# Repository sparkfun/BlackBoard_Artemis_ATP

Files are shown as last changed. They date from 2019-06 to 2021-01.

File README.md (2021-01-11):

**NOTE:** *This product has been retired from our catalog. There is an updated RedBoard version available: [DEV-15442](https://www.sparkfun.com/products/15442). If you are looking for more up-to-date info, please check out some of these resources to see how other users are still hacking and improving on this product version.*

* *[SparkFun Artemis Forum](https://forum.sparkfun.com/viewforum.php?f=167)*
* *[Comments Here on GitHub](https://github.com/sparkfun/BlackBoard_Artemis_ATP/issues)*

SparkFun BlackBoard Artemis ATP
============================

SparkFun BlackBoard Artemis ATP

[*SparkFun BlackBoard Artemis ATP (SPX-15412)*](https://www.sparkfun.com/products/15412)

The BlackBoard Artemis ATP is affectionately called 'All the Pins!' at SparkFun. The Artemis module has 48 GPIO and this board breaks out absolutely every one of them in a familiar Mega like form factor. What's with the silkscreen labels? They're all over the place. We decided to label the pins as they are assigned on the Apollo3 IC itself. This makes finding the pin with the function you desire a lot easier. Have a look at the [full pin map](https://cdn.sparkfun.com/assets/8/2/3/3/c/Apollo3_Pad_Mapping.pdf) from the Apollo3 datasheet. If you really need to test out the 4-bit SPI functionality of the Artemis you're going to need to access pins 4, 22, 23, and 26. Need to try out the differential ADC port 1? Pins 14 and 15. The BlackBoard Artemis ATP will allow you to flex the impressive capabilities of the Artemis module.

The BlackBoard Artemis ATP has the improved power conditioning and USB to serial that we've refined over the years on our BlackBoard line of products. A modern USB-C connector make programming easy. A Qwiic connector makes I<sup>2</sup>C easy. The ATP is fully compatible with SparkFun's Arduino core and can be programmed easily under the Arduino IDE. We've exposed the JTAG connector for more advanced users who prefer to use the power and speed of professional tools. If you need a *lot* of a GPIO with a simple to program, ready to go to market module, the ATP is the fix you need. We've added a digital MEMS microphone for folks wanting to experiment with always-on voice commands with TensorFlow and machine learning. We've even added a convenient jumper to measure current consumption for low power testing.

With 1M flash and 384k RAM you'll have plenty of room for your sketches. The Artemis module runs at 48MHz with a 96MHz turbo mode available and with Bluetooth to boot!

The SparkFun BlackBoard Artemis ATP is a powerful platform if you're interesting in testing out the full capabilities of the SparkFun Artemis module. If you're looking for more compact solution, be sure to checkout our Nano and Uno footprints for more hacker friendly products.

**Note:** We are actively working on getting FCC and compliance certifications for the SparkFun Artemis Module. Once our certifications are complete we will be moving the ATP to a RedBoard format with the FCC Certified version of the Artemis on board. *Please be aware* that this could happen as soon as a few weeks to a month so this BlackBoard version is for those of you who can't wait and want to start using the SparkFun Artemis as soon as possible!

Repository Contents
-------------------
* **/Hardware** - Eagle design files (.brd, .sch)

Documentation
-------------------
* **[BlackBoard Artemis ATP Hookup Guide](https://learn.sparkfun.com/tutorials/hookup-guide-for-the-blackboard-artemis-atp)** - Hookup Guide for the BlackBoard Artemis ATP
* **[Designing with the SparkFun Artemis](https://learn.sparkfun.com/tutorials/designing-with-the-sparkfun-artemis)** - Layout and design considerations when using the Artemis module.
* **[Artemis Development with Arduino](https://learn.sparkfun.com/tutorials/artemis-development-with-arduino)** - Introduction to the Arduino core for the Artemis Module.
* **[Ambiq Apollo3 SDK SetUp](https://learn.sparkfun.com/tutorials/using-sparkfun-edge-board-with-ambiq-apollo3-sdk)** - Getting set up with the Apollo3 Software Development Kit.
* **[CH340E USB to serial IC Drivers](https://www.sparkfun.com/ch340)**

License Information
-------------------

This product is _**open source**_! 

Please review the LICENSE.md file for license information. 

If you have any questions or concerns on licensing, please contact techsupport@sparkfun.com.

Please use, reuse, and modify these files as you see fit. Please maintain attribution to SparkFun Electronics and release any derivative under the same license.

Distributed as-is; no warranty is given.

- Your friends at SparkFun.

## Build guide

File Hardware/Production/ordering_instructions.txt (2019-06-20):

panel size, 226x175mm
PCB thickness, 1.6mm
number of layers, 2
soldermask color, Red
silkscreen color, White
oz copper, 1oz
finish, HASL lead free
stencils, top
pcs per panel, 6
min trace width, 0.177800mm / 0.007000in
min drill size, 0.304800mm / 0.012000in

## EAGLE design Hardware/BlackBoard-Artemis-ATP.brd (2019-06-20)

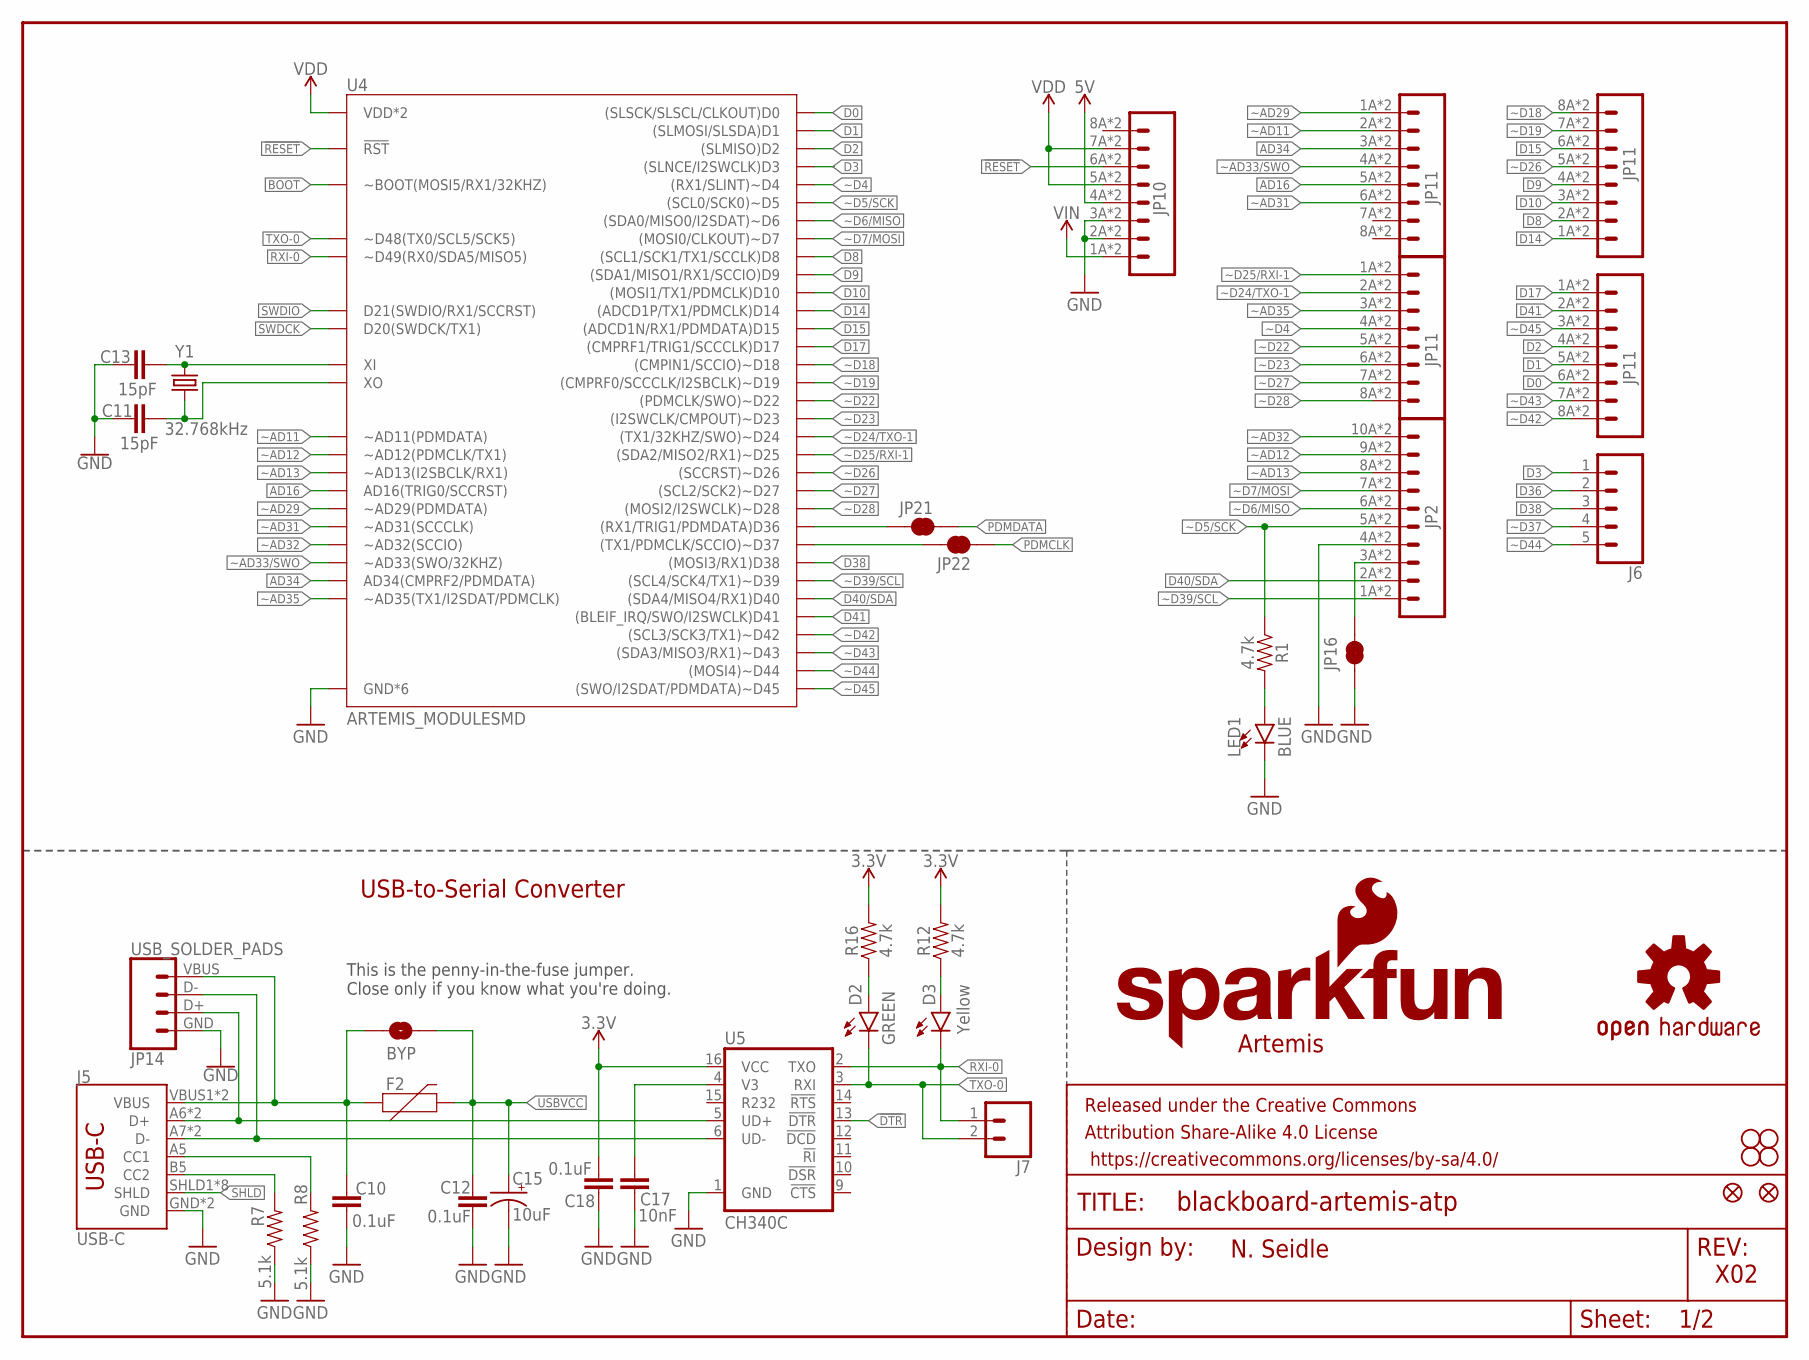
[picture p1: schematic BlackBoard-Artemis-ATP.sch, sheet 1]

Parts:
BYP: BYP; SMT-JUMPER_2_NO_SILK
C10, C12, C18: 0.1uF; 0603
C11, C13: 15pF; 0603
C15: 10uF; EIA3216
C17: 10nF; 0603
D2: GREEN; LED-1206
D3: Yellow; LED-1206
F2: 6V/2A; 1210
FRAME1: FRAME-LETTER; CREATIVE_COMMONS
J5: USB-C; USB-C-16P
J6: CONN_05NO_SILK; 1X05_NO_SILK
J7: CONN_021X02_NO_SILK; 1X02_NO_SILK
JP1: SFE_LOGO_NAME.1_INCH; SFE_LOGO_NAME_.1
JP2: M10SMD_COMBO; 1X10_SMD_COMBINED
JP3, JP4, JP5, JP6: STAND-OFF
JP7: SFE_LOGO_FLAME.1_INCH; SFE_LOGO_FLAME_.1
JP8, JP9: FIDUCIAL1X2; FIDUCIAL-1X2
JP10: M08SMD-COMBO; 1X08_SMD_COMBINED
JP11, JP13, JP19, JP20: JP11; 1X08_SMD_COMBINED
JP14: USB_SOLDER_PADS; USB-SOLDER-PADS
JP16, JP21, JP22: JUMPER-SMT_2_NC_TRACE_SILK; SMT-JUMPER_2_NC_TRACE_SILK
LED1: BLUE; LED-1206
R1, R12, R16: 4.7k; 0603
R7, R8: 5.1k; 0603
U4: ARTEMIS_MODULESMD; ARTEMIS_FP
U5: CH340C; SO016
U$16: OSHW-LOGOS; OSHW-LOGO-S
Y1: 32.768kHz; CRYSTAL-SMD-3.2X1.5MM

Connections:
3.3V: C18.1, R12.2, R16.2, U5.16 (VCC); also elsewhere on the board
5V: JP10.4A (4), JP10.4B (4); also elsewhere on the board
!DTR: U5.13 (!DTR); also elsewhere on the board
!RESET: JP10.6A (6), JP10.6B (6), U4.~RST (!RST); also elsewhere on the board
AD16: JP13.5A (5), JP13.5B (5), U4.AD16 (AD16(TRIG0/SCCRST))
AD34: JP13.3A (3), JP13.3B (3), U4.AD34 (AD34(CMPRF2/PDMDATA))
BOOT: U4.BOOT (~BOOT(MOSI5/RX1/32KHZ)); also elsewhere on the board
CC1: J5.A5 (CC1), R8.2
CC2: J5.B5 (CC2), R7.2
D0: JP20.6A (6), JP20.6B (6), U4.D0 ((SLSCK/SLSCL/CLKOUT)D0)
D1: JP20.5A (5), JP20.5B (5), U4.D1 ((SLMOSI/SLSDA)D1)
D2: JP20.4A (4), JP20.4B (4), U4.D2 ((SLMISO)D2)
D3: J6.1, U4.D3 ((SLNCE/I2SWCLK)D3)
D8: JP19.2A (2), JP19.2B (2), U4.D8 ((SCL1/SCK1/TX1/SCCLK)D8)
D9: JP19.4A (4), JP19.4B (4), U4.D9 ((SDA1/MISO1/RX1/SCCIO)D9)
D10: JP19.3A (3), JP19.3B (3), U4.D10 ((MOSI1/TX1/PDMCLK)D10)
D14: JP19.1A (1), JP19.1B (1), U4.D14 ((ADCD1P/TX1/PDMCLK)D14)
D15: JP19.6A (6), JP19.6B (6), U4.D15 ((ADCD1N/RX1/PDMDATA)D15)
D17: JP20.1A (1), JP20.1B (1), U4.D17 ((CMPRF1/TRIG1/SCCCLK)D17)
D36: J6.2, JP21.1, U4.D36 ((RX1/TRIG1/PDMDATA)D36)
D38: J6.3, U4.D38 ((MOSI3/RX1)D38)
D40/SDA: JP2.2A (2), JP2.2B (2), U4.D40 ((SDA4/MISO4/RX1)D40); also elsewhere on the board
D41: JP20.2A (2), JP20.2B (2), U4.D41 ((BLEIF_IRQ/SWO/I2SWCLK)D41)
D+: J5.A6 (D+), J5.B6 (D+), JP14.D+ (3), U5.5 (UD+)
D-: J5.A7 (D-), J5.B7 (D-), JP14.D- (2), U5.6 (UD-)
GND: C10.2, C11.1, C12.2, C13.1, C15.-, C17.2, C18.2, J5.GND, J5.GND2 (GND), JP2.4A (4), JP2.4B (4), JP10.2A (2), JP10.2B (2), JP10.3A (3), JP10.3B (3), JP14.GND (4), JP16.1, LED1.C, R7.1, R8.1, U4.GND@1 (GND*6), U4.GND@22 (GND*6), U4.GND@38 (GND*6), U4.GND@39 (GND*6), U4.GND@47 (GND*6), U4.GND@59 (GND*6), U5.1 (GND); also elsewhere on the board
unnamed: LED1.A, R1.2
unnamed: D2.A, R16.1
unnamed: C17.1, U5.4 (V3)
unnamed: C11.2, U4.XO, Y1.P$2 (2)
unnamed: C13.2, U4.XI, Y1.P$1 (1)
unnamed: D3.A, R12.1
unnamed: JP2.3A (3), JP2.3B (3), JP16.2
PDMCLK: JP22.2; also elsewhere on the board
PDMDATA: JP21.2; also elsewhere on the board
RXI-0: D3.C, J7.1, U4.RXI-0 (~D49(RX0/SDA5/MISO5)), U5.2 (TXO)
SHLD: J5.SHLD1 (SHLD), J5.SHLD2 (SHLD), J5.SHLD3 (SHLD), J5.SHLD4 (SHLD), J5.SHLD5 (SHLD), J5.SHLD6 (SHLD), J5.SHLD7 (SHLD), J5.SHLD8 (SHLD)
SWDCK: U4.SWDCK (D20(SWDCK/TX1)); also elsewhere on the board
SWDIO: U4.SWDIO (D21(SWDIO/RX1/SCCRST)); also elsewhere on the board
TXO-0: D2.C, J7.2, U4.TXO-0 (~D48(TX0/SCL5/SCK5)), U5.3 (RXI)
USBVCC: BYP.2, C12.1, C15.+, F2.2; also elsewhere on the board
VDD: JP10.5A (5), JP10.5B (5), JP10.7A (7), JP10.7B (7), U4.VDD@36 (VDD*2), U4.VDD@37 (VDD*2); also elsewhere on the board
VIN: JP10.1A (1), JP10.1B (1); also elsewhere on the board
VUSB: BYP.1, C10.1, F2.1, J5.VBUS1 (VBUS), J5.VBUS2 (VBUS), JP14.VBUS (1)
~AD11: JP13.2A (2), JP13.2B (2), U4.~AD11 (~AD11(PDMDATA))
~AD12: JP2.9A (9), JP2.9B (9), U4.~AD12 (~AD12(PDMCLK/TX1))
~AD13: JP2.8A (8), JP2.8B (8), U4.~AD13 (~AD13(I2SBCLK/RX1))
~AD29: JP13.1A (1), JP13.1B (1), U4.~AD29 (~AD29(PDMDATA))
~AD31: JP13.6A (6), JP13.6B (6), U4.~AD31 (~AD31(SCCCLK))
~AD32: JP2.10A (10), JP2.10B (10), U4.~AD32 (~AD32(SCCIO))
~AD33/SWO: JP13.4A (4), JP13.4B (4), U4.~AD33/SWO (~AD33(SWO/32KHZ)); also elsewhere on the board
~AD35: JP11.3A (3), JP11.3B (3), U4.~AD35 (~AD35(TX1/I2SDAT/PDMCLK))
~D4: JP11.4A (4), JP11.4B (4), U4.~D4 ((RX1/SLINT)~D4)
~D5/SCK: JP2.5A (5), JP2.5B (5), R1.1, U4.~D5 ((SCL0/SCK0)~D5)
~D6/MISO: JP2.6A (6), JP2.6B (6), U4.~D6 ((SDA0/MISO0/I2SDAT)~D6)
~D7/MOSI: JP2.7A (7), JP2.7B (7), U4.D7 ((MOSI0/CLKOUT)~D7)
~D18: JP19.8A (8), JP19.8B (8), U4.~D18 ((CMPIN1/SCCIO)~D18)
~D19: JP19.7A (7), JP19.7B (7), U4.~D19 ((CMPRF0/SCCCLK/I2SBCLK)~D19)
~D22: JP11.5A (5), JP11.5B (5), U4.~D22 ((PDMCLK/SWO)~D22)
~D23: JP11.6A (6), JP11.6B (6), U4.~D23 ((I2SWCLK/CMPOUT)~D23)
~D24/TXO-1: JP11.2A (2), JP11.2B (2), U4.~D24 ((TX1/32KHZ/SWO)~D24)
~D25/RXI-1: JP11.1A (1), JP11.1B (1), U4.~D25 ((SDA2/MISO2/RX1)~D25)
~D26: JP19.5A (5), JP19.5B (5), U4.~D26 ((SCCRST)~D26)
~D27: JP11.7A (7), JP11.7B (7), U4.~D27 ((SCL2/SCK2)~D27)
~D28: JP11.8A (8), JP11.8B (8), U4.~D28 ((MOSI2/I2SWCLK)~D28)
~D37: J6.4, JP22.1, U4.~D37 ((TX1/PDMCLK/SCCIO)~D37)
~D39/SCL: JP2.1A (1), JP2.1B (1), U4.~D39 ((SCL4/SCK4/TX1)~D39); also elsewhere on the board
~D42: JP20.8A (8), JP20.8B (8), U4.~D42 ((SCL3/SCK3/TX1)~D42)
~D43: JP20.7A (7), JP20.7B (7), U4.~D43 ((SDA3/MISO3/RX1)~D43)
~D44: J6.5, U4.~D44 ((MOSI4)~D44)
~D45: JP20.3A (3), JP20.3B (3), U4.~D45 ((SWO/I2SDAT/PDMDATA)~D45)

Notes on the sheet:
Artemis
USB-to-Serial Converter
N. Seidle
X02
This is the penny-in-the-fuse jumper. Close only if you know what you're doing.

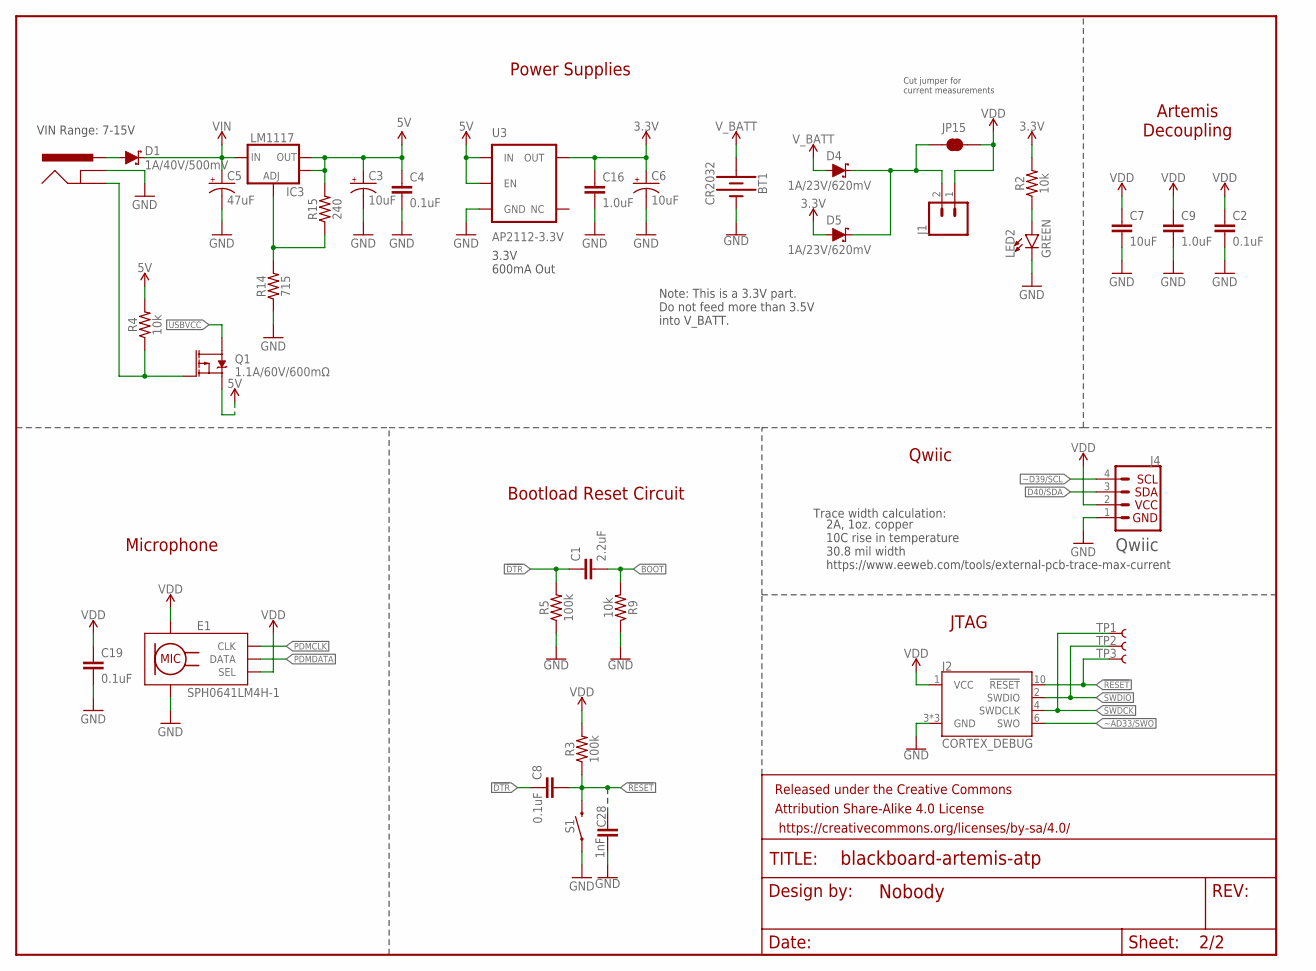
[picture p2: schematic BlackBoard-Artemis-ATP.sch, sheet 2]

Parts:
BT1: CR2032; BATTCON_20MM_4LEGS_OVERPASTE
C1: 2.2uF; 0603
C2, C4, C8, C19: 0.1uF; 0603
C3, C6: 10uF; EIA3216
C5: 47uF; PANASONIC_D
C7: 10uF; 0603
C9, C16: 1.0uF; 0603
C28: 1nF; 0603
D1: 1A/40V/500mV; SMA-DIODE
D4, D5: 1A/23V/620mV; SOD-323
E1: SPH0641LM4H-1; SPH0641LM4H-1_MICROPHONE
FRAME2: FRAME-LETTERNO_PACKAGE; DUMMY
IC3: LM1117; SOT223-ALT1
J1: CONN_021X02_NO_SILK; 1X02_NO_SILK
J2: CORTEX_DEBUG; 2X5-PTH-1.27MM-NO_SILK
J3: POWER_JACKTOE; POWER_JACK_SMD_OVERPASTE_TOE
J4: QWIIC_CONNECTORJS-1MM; JST04_1MM_RA
JP15: JUMPER-SMT_2_NC_TRACE_SILK; SMT-JUMPER_2_NC_TRACE_SILK
LED2: GREEN; LED-1206
Q1: 1.1A/60V/600mΩ; SOT23-3
R2, R4, R9: 10k; 0603
R3, R5: 100k; 0603
R14: 715; 0603
R15: 240; 0603
S1: MOMENTARY-SWITCH-SPST-SMD-5.2-TALL-REDUNDANT; TACTILE_SWITCH_SMD_5.2MM
TP1, TP2, TP3: TEST-POINT3X5; PAD.03X.05
U3: AP2112-3.3V; SOT23-5

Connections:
3.3V: C6.+, C16.1, D5.A, R2.2, U3.5 (OUT); also elsewhere on the board
5V: C3.+, C4.1, IC3.2 (OUT), IC3.4 (OUT), Q1.2 (S), R4.2, R15.2, U3.1 (IN), U3.3 (EN); also elsewhere on the board
!DTR: C1.1, C8.1, R5.2; also elsewhere on the board
!RESET: C8.2, C28.1, J2.10 (!RESET), R3.1, S1.3 (2), S1.4 (2), TP3.P$1; also elsewhere on the board
BOOT: C1.2, R9.2; also elsewhere on the board
D40/SDA: J4.3; also elsewhere on the board
GND: BT1.2 (-), C2.1, C3.-, C4.2, C5.-, C6.-, C7.2, C9.2, C16.2, C19.2, C28.2, E1.3 (GND), E1.6 (GND), E1.7 (GND), E1.8 (GND), J2.3 (GND), J2.5 (GND), J2.9 (GND), J3.GND (GNDBREAK), J4.1, LED2.C, R5.1, R9.1, R14.1, S1.1, S1.2 (1), U3.2 (GND); also elsewhere on the board
INSERT: J3.P$4 (GND), Q1.1 (G), R4.1
unnamed: LED2.A, R2.1
unnamed: D4.C, D5.C, J1.2, JP15.1
unnamed: IC3.1 (ADJ), R14.2, R15.1
PDMCLK: E1.4 (CLK); also elsewhere on the board
PDMDATA: E1.1 (DATA); also elsewhere on the board
PWRIN: D1.A, J3.VIN0 (PWR)
SWDCK: J2.4 (SWDCLK), TP1.P$1; also elsewhere on the board
SWDIO: J2.2 (SWDIO), TP2.P$1; also elsewhere on the board
USBVCC: Q1.3 (D); also elsewhere on the board
VDD: C2.2, C7.1, C9.1, C19.1, E1.2 (SEL), E1.5 (VDD), J1.1, J2.1 (VCC), J4.2, JP15.2, R3.2; also elsewhere on the board
VIN: C5.+, D1.C, IC3.3 (IN); also elsewhere on the board
V_BATT: BT1.1 (+), D4.A
~AD33/SWO: J2.6 (SWO); also elsewhere on the board
~D39/SCL: J4.4; also elsewhere on the board

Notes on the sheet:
VIN Range: 7-15V
3.3V 600mA Out
Cut jumper for current measurements
Power Supplies
Microphone
Note: This is a 3.3V part. Do not feed more than 3.5V into V_BATT.
Qwiic
Trace width calculation:
2A, 1oz. copper 10C rise in temperature 30.8 mil width https://www.eeweb.com/tools/external-pcb-trace-max-current
Bootload Reset Circuit
JTAG
Artemis Decoupling

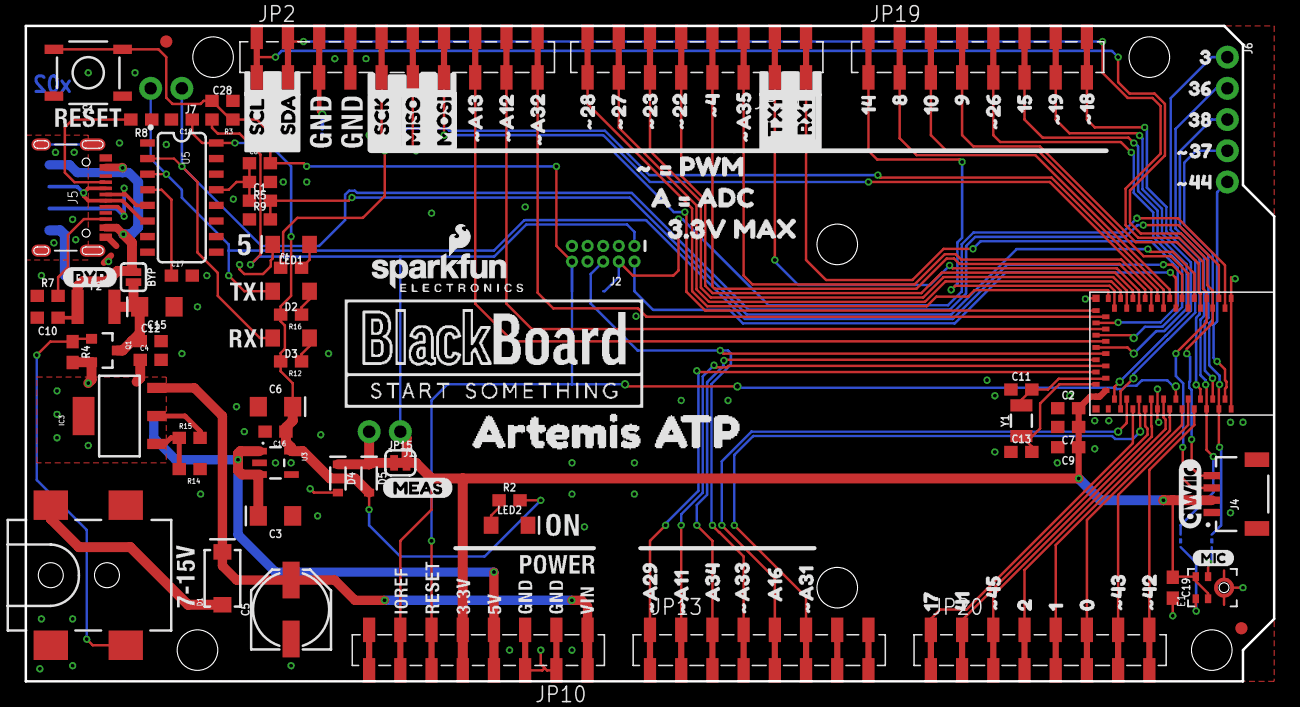
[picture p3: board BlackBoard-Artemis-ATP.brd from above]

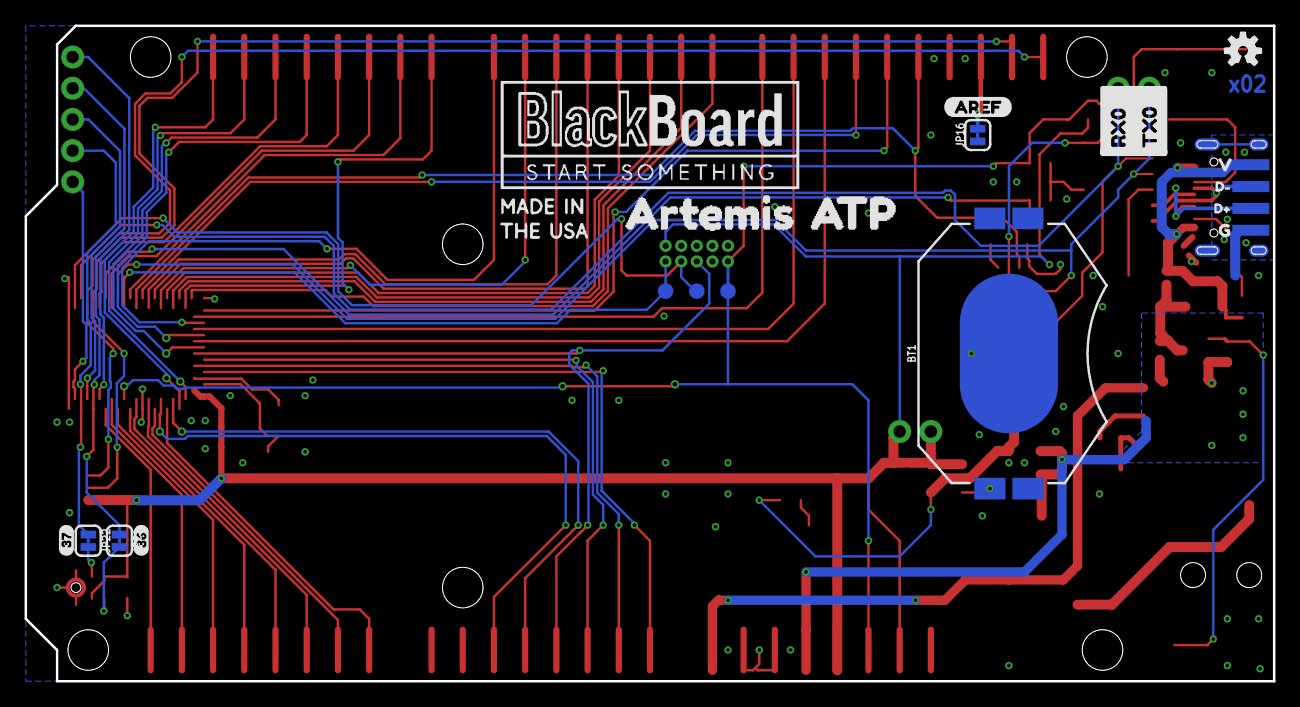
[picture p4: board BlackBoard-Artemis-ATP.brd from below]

Board: 2 copper layers, 101.6 x 53.3 mm, 149 parts (23 on the bottom side), 77 nets.

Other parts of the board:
JP17, JP18: STAND-OFF
U$1, U$3: BLACKBOARDLOGO#PNG
U$2: D#3
U$4: MADEINUSA#PNG
U$9: QWIIC_COPYRIGHT_SMALL
U$10: D#4
U$11: G1
U$12: V0
U$13: #A332
U$14, U$15: ARTEMIS0
U$17: A160
U$18: SCL1
U$19: #48
U$20: AREF2
U$21: #229
U$22: SDA0
U$23: #3711
U$24: #187
U$25: #2310
U$26: #2711
U$27: #2812
U$28, U$61: ATP1
U$29: #A113
U$30: #A294
U$31: #A310
U$32: #196
U$33: #A357
U$34: #A1214
U$35: #A1315
U$36: #A3213
U$37: #264
U$38: A342
U$39: #4213
U$40: #4314
U$41: #4412
U$42: #4518
U$43: 015
U$44: 38
U$45: 81
U$46: 93
U$47: MISO8
U$48: MOSI7
U$49: RX01
U$50: SCK9
U$51: 102
U$52: 116
U$53: TX00
U$54: 140
U$55: 155
U$56: 217
U$57: 369
U$58: 1720
U$59: 3810
U$60: 4119
U$62: MIC0
U$63: 364
U$64: 373
U$66: #_#_PWM7
U$67: 3#3V_MAX2
U$68: BYP0
U$69: A_#_ADC6
U$70: MEAS3
U$71: RX11
U$72: TX10

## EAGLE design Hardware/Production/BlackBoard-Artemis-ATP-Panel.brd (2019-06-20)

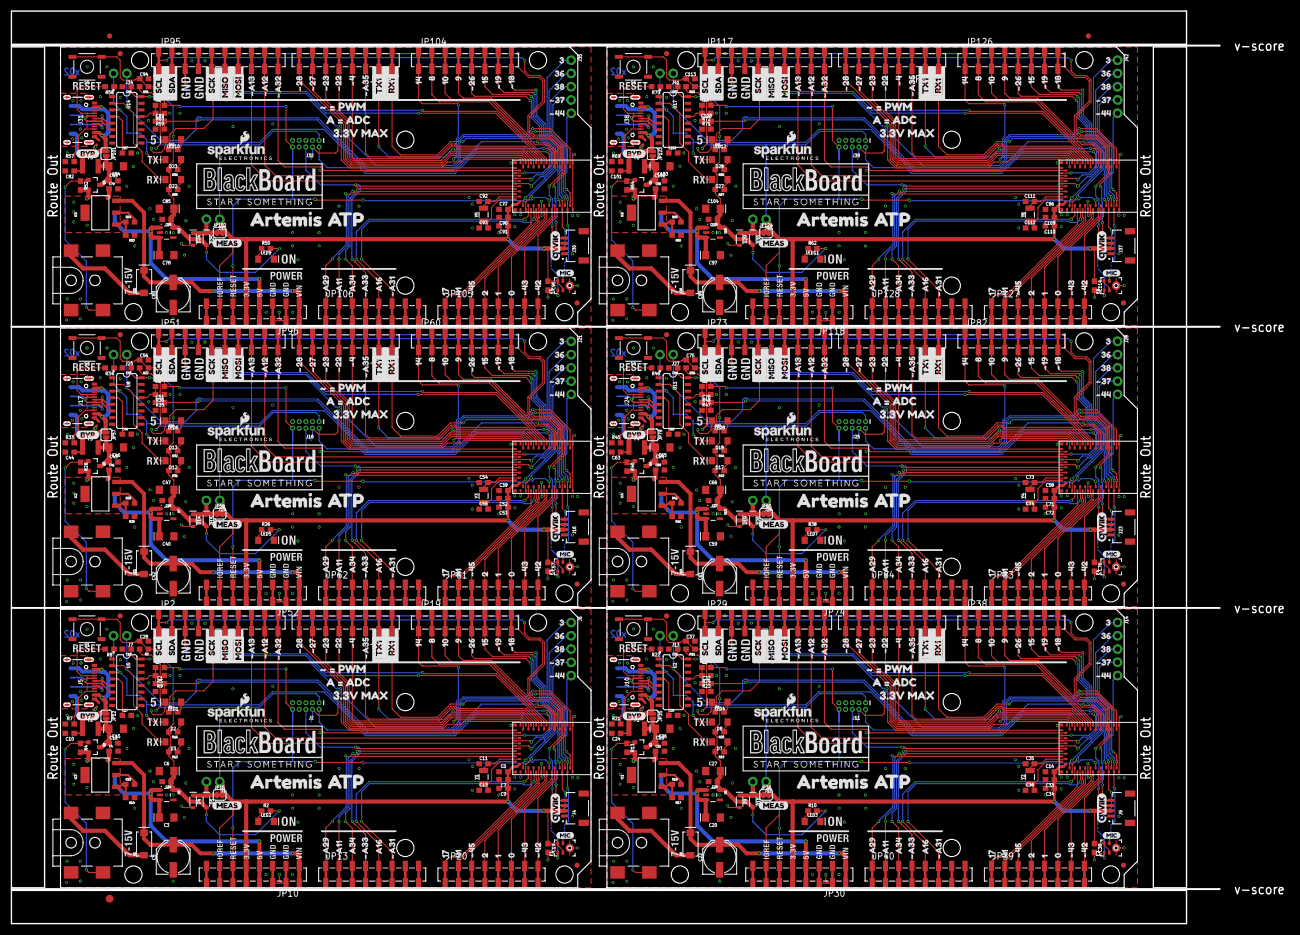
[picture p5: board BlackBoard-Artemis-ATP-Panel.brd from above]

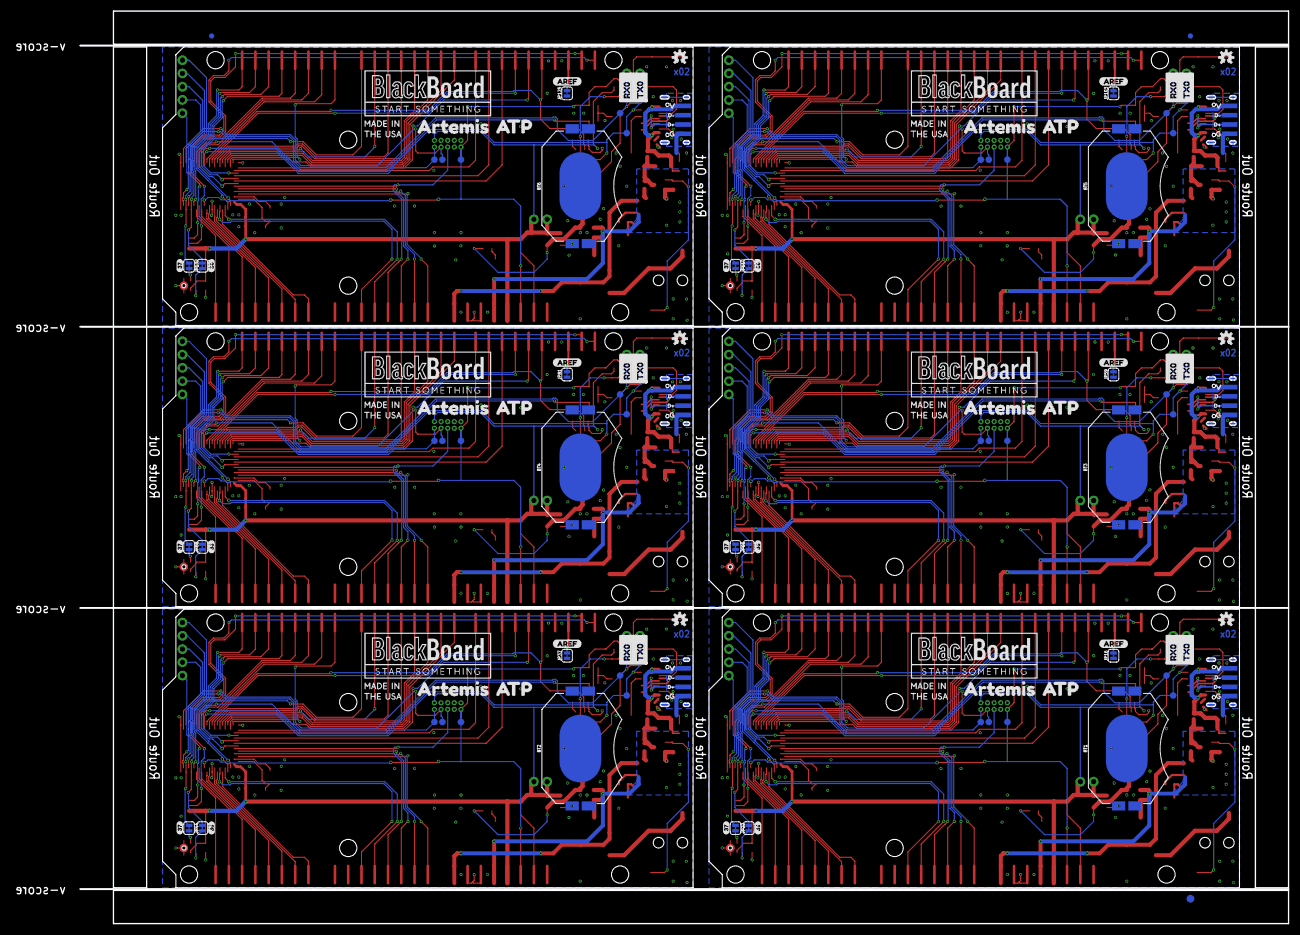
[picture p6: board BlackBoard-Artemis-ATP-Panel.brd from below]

Board: 2 copper layers, 231.4 x 174.8 mm, 906 parts (153 on the bottom side), 462 nets.

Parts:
BT1, BT2, BT3, BT4, BT5, BT6: CR2032; BATTCON_20MM_4LEGS_OVERPASTE
C1, C32, C51, C70, C89, C108: 2.2uF; 0603
C2, C4, C8, C10, C12, C14, C18, C19, C21, C23, C24, C25, C31, C38, C39, C41, C43, C44, C45, C50, C57, C58, C60, C62, C63, C64, C69, C76, C77, C79, C81, C82, C83, C88, C95, C96, C98, C100, C101, C102, C107, C114: 0.1uF; 0603
C3, C6, C15, C20, C26, C27, C40, C46, C47, C59, C65, C66, C78, C84, C85, C97, C103, C104: 10uF; EIA3216
C5, C22, C42, C61, C80, C99: 47uF; PANASONIC_D
C7, C33, C52, C71, C90, C109: 10uF; 0603
C9, C16, C29, C34, C48, C53, C67, C72, C86, C91, C105, C110: 1.0uF; 0603
C11, C13, C35, C36, C54, C55, C73, C74, C92, C93, C111, C112: 15pF; 0603
C17, C30, C49, C68, C87, C106: 10nF; 0603
C28, C37, C56, C75, C94, C113: 1nF; 0603
D1, D6, D11, D16, D21, D26: 1A/40V/500mV; SMA-DIODE
D2, D8, D13, D18, D23, D28: GREEN; LED-1206
D3, D7, D12, D17, D22, D27: Yellow; LED-1206
D4, D5, D9, D10, D14, D15, D19, D20, D24, D25, D29, D30: 1A/23V/620mV; SOD-323
E1, E2, E3, E4, E5, E6: SPH0641LM4H-1; SPH0641LM4H-1_MICROPHONE
E$1, E$2, E$3, E$4: FIDUCIAL-1X2
E$5, E$6: FIDUCIAL-1.5X3
F1, F2, F3, F4, F5, F6: 6V/2A; 1210
FRAME1, FRAME2, FRAME3, FRAME4, FRAME5, FRAME6: FRAME-LETTERNO_PACKAGE; DUMMY
IC1, IC2, IC3, IC4, IC5, IC6: LM1117; SOT223-ALT1
J1, J7, J12, J13, J19, J20, J26, J27, J33, J34, J40, J41: 1X02_NO_SILK
J2, J11, J18, J25, J32, J39: CORTEX_DEBUG; 2X5-PTH-1.27MM-NO_SILK
J3, J8, J15, J22, J29, J36: POWER_JACKTOE; POWER_JACK_SMD_OVERPASTE_TOE
J4, J9, J16, J23, J30, J37: JST04_1MM_RA
J5, J10, J17, J24, J31, J38: USB-C; USB-C-16P
J6, J14, J21, J28, J35, J42: 1X05_NO_SILK
JP1, JP31, JP53, JP75, JP97, JP119: SFE_LOGO_NAME.1_INCH; SFE_LOGO_NAME_.1
JP2, JP29, JP51, JP73, JP95, JP117: M10SMD_COMBO; 1X10_SMD_COMBINED
JP3, JP4, JP5, JP6, JP17, JP18, JP23, JP24, JP25, JP26, JP41, JP42, JP45, JP46, JP47, JP48, JP63, JP64, JP67, JP68, JP69, JP70, JP85, JP86, JP89, JP90, JP91, JP92, JP107, JP108, JP111, JP112, JP113, JP114, JP129, JP130: STAND-OFF
JP7, JP32, JP54, JP76, JP98, JP120: SFE_LOGO_FLAME.1_INCH; SFE_LOGO_FLAME_.1
JP8, JP9, JP27, JP28, JP49, JP50, JP71, JP72, JP93, JP94, JP115, JP116: FIDUCIAL1X2; FIDUCIAL-1X2
JP10, JP30, JP52, JP74, JP96, JP118: 1X08_SMD_COMBINED
JP11, JP13, JP19, JP20, JP33, JP38, JP39, JP40, JP55, JP60, JP61, JP62, JP77, JP82, JP83, JP84, JP99, JP104, JP105, JP106, JP121, JP126, JP127, JP128: JP11; 1X08_SMD_COMBINED
JP12, JP35, JP57, JP79, JP101, JP123: SMT-JUMPER_2_NO_SILK
JP14, JP34, JP56, JP78, JP100, JP122: USB_SOLDER_PADS; USB-SOLDER-PADS
JP15, JP16, JP21, JP22, JP36, JP37, JP43, JP44, JP58, JP59, JP65, JP66, JP80, JP81, JP87, JP88, JP102, JP103, JP109, JP110, JP124, JP125, JP131, JP132: SMT-JUMPER_2_NC_TRACE_SILK
LED1, LED4, LED6, LED8, LED10, LED12: BLUE; LED-1206
LED2, LED3, LED5, LED7, LED9, LED11: GREEN; LED-1206
Q1, Q2, Q3, Q4, Q5, Q6: 1.1A/60V/600mΩ; SOT23-3
R1, R6, R12, R16, R19, R20, R25, R31, R32, R37, R43, R44, R49, R55, R56, R61, R67, R68: 4.7k; 0603
R2, R4, R9, R10, R13, R23, R26, R28, R35, R38, R40, R47, R50, R52, R59, R62, R64, R71: 10k; 0603
R3, R5, R11, R24, R27, R36, R39, R48, R51, R60, R63, R72: 100k; 0603
R7, R8, R21, R22, R33, R34, R45, R46, R57, R58, R69, R70: 5.1k; 0603
R14, R17, R29, R41, R53, R65: 715; 0603
R15, R18, R30, R42, R54, R66: 240; 0603
S1, S2, S3, S4, S5, S6: TACTILE_SWITCH_SMD_5.2MM
TP1, TP2, TP3, TP4, TP7, TP10, TP11, TP12, TP15, TP16, TP17, TP20, TP21, TP22, TP25, TP26, TP27, TP30: PAD.03X.05
TP5, TP6, TP8, TP9, TP13, TP14, TP18, TP19, TP23, TP24, TP28, TP29: TEST-POINT3X5; PAD.03X.05
U1, U3, U7, U10, U13, U16: AP2112-3.3V; SOT23-5
U2, U5, U8, U11, U14, U17: CH340C; SO016
U4, U6, U9, U12, U15, U18: ARTEMIS_MODULESMD; ARTEMIS_FP
U$1, U$3, U$6, U$7, U$136, U$137, U$203, U$204, U$270, U$271, U$337, U$338: BLACKBOARDLOGO#PNG
U$2, U$75, U$142, U$209, U$276, U$343: D#3
U$4, U$8, U$138, U$205, U$272, U$339: MADEINUSA#PNG
U$5, U$16, U$135, U$202, U$269, U$336: OSHW-LOGOS; OSHW-LOGO-S
U$9, U$65, U$139, U$206, U$273, U$340: QWIIC_COPYRIGHT_SMALL
U$10, U$76, U$143, U$210, U$277, U$344: D#4
U$11, U$73, U$140, U$207, U$274, U$341: G1
U$12, U$74, U$141, U$208, U$275, U$342: V0
U$13, U$133, U$200, U$267, U$334, U$401: #A332
U$14, U$15, U$77, U$78, U$144, U$145, U$211, U$212, U$278, U$279, U$345, U$346: ARTEMIS0
U$17, U$79, U$146, U$213, U$280, U$347: A160
U$18, U$105, U$172, U$239, U$306, U$373: SCL1
U$19, U$80, U$147, U$214, U$281, U$348: #48
U$20, U$104, U$171, U$238, U$305, U$372: AREF2
U$21, U$81, U$148, U$215, U$282, U$349: #229
U$22, U$106, U$173, U$240, U$307, U$374: SDA0
U$23, U$110, U$177, U$244, U$311, U$378: #3711
U$24, U$107, U$174, U$241, U$308, U$375: #187
U$25, U$82, U$149, U$216, U$283, U$350: #2310
U$26, U$83, U$150, U$217, U$284, U$351: #2711
U$27, U$84, U$151, U$218, U$285, U$352: #2812
U$28, U$61, U$128, U$134, U$195, U$201, U$262, U$268, U$329, U$335, U$396, U$402: ATP1
U$29, U$85, U$152, U$219, U$286, U$353: #A113
U$30, U$86, U$153, U$220, U$287, U$354: #A294
U$31, U$87, U$154, U$221, U$288, U$355: #A310
U$32, U$108, U$175, U$242, U$309, U$376: #196
U$33, U$88, U$155, U$222, U$289, U$356: #A357
U$34, U$89, U$156, U$223, U$290, U$357: #A1214
U$35, U$90, U$157, U$224, U$291, U$358: #A1315
U$36, U$91, U$158, U$225, U$292, U$359: #A3213
U$37, U$109, U$176, U$243, U$310, U$377: #264
U$38, U$92, U$159, U$226, U$293, U$360: A342
U$39, U$111, U$178, U$245, U$312, U$379: #4213
U$40, U$112, U$179, U$246, U$313, U$380: #4314
U$41, U$113, U$180, U$247, U$314, U$381: #4412
U$42, U$114, U$181, U$248, U$315, U$382: #4518
U$43, U$115, U$182, U$249, U$316, U$383: 015
U$44, U$116, U$183, U$250, U$317, U$384: 38
U$45, U$117, U$184, U$251, U$318, U$385: 81
U$46, U$118, U$185, U$252, U$319, U$386: 93
U$47, U$93, U$160, U$227, U$294, U$361: MISO8
U$48, U$94, U$161, U$228, U$295, U$362: MOSI7
U$49, U$102, U$169, U$236, U$303, U$370: RX01
U$50, U$95, U$162, U$229, U$296, U$363: SCK9
U$51, U$119, U$186, U$253, U$320, U$387: 102
U$52, U$120, U$187, U$254, U$321, U$388: 116
U$53, U$103, U$170, U$237, U$304, U$371: TX00
U$54, U$121, U$188, U$255, U$322, U$389: 140
U$55, U$122, U$189, U$256, U$323, U$390: 155
U$56, U$123, U$190, U$257, U$324, U$391: 217
U$57, U$124, U$191, U$258, U$325, U$392: 369
U$58, U$125, U$192, U$259, U$326, U$393: 1720
U$59, U$126, U$193, U$260, U$327, U$394: 3810
U$60, U$127, U$194, U$261, U$328, U$395: 4119
U$62, U$129, U$196, U$263, U$330, U$397: MIC0
U$63, U$130, U$197, U$264, U$331, U$398: 364
U$64, U$131, U$198, U$265, U$332, U$399: 373
U$66, U$96, U$163, U$230, U$297, U$364: #_#_PWM7
U$67, U$97, U$164, U$231, U$298, U$365: 3#3V_MAX2
U$68, U$132, U$199, U$266, U$333, U$400: BYP0
U$69, U$98, U$165, U$232, U$299, U$366: A_#_ADC6
U$70, U$99, U$166, U$233, U$300, U$367: MEAS3
U$71, U$100, U$167, U$234, U$301, U$368: RX11
U$72, U$101, U$168, U$235, U$302, U$369: TX10
Y1, Y2, Y3, Y4, Y5, Y6: 32.768kHz; CRYSTAL-SMD-3.2X1.5MM

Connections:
3.3V: C6.+, C16.1, C18.1, D5.A, R2.2, R12.2, R16.2, U3.5, U5.16
3.3V1: C27.+, C29.1, C31.1, D10.A, R10.2, R19.2, R20.2, U1.5, U2.16
3.3V2: C47.+, C48.1, C50.1, D15.A, R26.2, R31.2, R32.2, U7.5, U8.16
3.3V3: C66.+, C67.1, C69.1, D20.A, R38.2, R43.2, R44.2, U10.5, U11.16
3.3V4: C85.+, C86.1, C88.1, D25.A, R50.2, R55.2, R56.2, U13.5, U14.16
3.3V5: C104.+, C105.1, C107.1, D30.A, R62.2, R67.2, R68.2, U16.5, U17.16
5V: C3.+, C4.1, IC3.2, IC3.4, JP10.4A, JP10.4B, Q1.2, R4.2, R15.2, U3.1, U3.3
5V1: C20.+, C21.1, IC1.2, IC1.4, JP30.4A, JP30.4B, Q2.2, R13.2, R18.2, U1.1, U1.3
5V2: C40.+, C41.1, IC2.2, IC2.4, JP52.4A, JP52.4B, Q3.2, R28.2, R30.2, U7.1, U7.3
5V3: C59.+, C60.1, IC4.2, IC4.4, JP74.4A, JP74.4B, Q4.2, R40.2, R42.2, U10.1, U10.3
5V4: C78.+, C79.1, IC5.2, IC5.4, JP96.4A, JP96.4B, Q5.2, R52.2, R54.2, U13.1, U13.3
5V5: C97.+, C98.1, IC6.2, IC6.4, JP118.4A, JP118.4B, Q6.2, R64.2, R66.2, U16.1, U16.3
!DTR: C1.1, C8.1, R5.2, U5.13
!DTR1: C23.1, C32.1, R24.2, U2.13
!DTR2: C43.1, C51.1, R36.2, U8.13
!DTR3: C62.1, C70.1, R48.2, U11.13
!DTR4: C81.1, C89.1, R60.2, U14.13
!DTR5: C100.1, C108.1, R72.2, U17.13
!RESET: C8.2, C28.1, J2.10, JP10.6A, JP10.6B, R3.1, S1.3, S1.4, TP3.P$1, U4.~RST
!RESET1: C23.2, C37.1, J11.10, JP30.6A, JP30.6B, R11.1, S2.3, S2.4, TP10.P$1, U6.~RST
!RESET2: C43.2, C56.1, J18.10, JP52.6A, JP52.6B, R27.1, S3.3, S3.4, TP15.P$1, U9.~RST
!RESET3: C62.2, C75.1, J25.10, JP74.6A, JP74.6B, R39.1, S4.3, S4.4, TP20.P$1, U12.~RST
!RESET4: C81.2, C94.1, J32.10, JP96.6A, JP96.6B, R51.1, S5.3, S5.4, TP25.P$1, U15.~RST
!RESET5: C100.2, C113.1, J39.10, JP118.6A, JP118.6B, R63.1, S6.3, S6.4, TP30.P$1, U18.~RST
AD1: JP40.5A, JP40.5B, U6.AD16
AD2: JP40.3A, JP40.3B, U6.AD34
AD3: JP62.5A, JP62.5B, U9.AD16
AD4: JP62.3A, JP62.3B, U9.AD34
AD5: JP84.5A, JP84.5B, U12.AD16
AD6: JP84.3A, JP84.3B, U12.AD34
AD7: JP106.5A, JP106.5B, U15.AD16
AD8: JP106.3A, JP106.3B, U15.AD34
AD9: JP128.5A, JP128.5B, U18.AD16
AD10: JP128.3A, JP128.3B, U18.AD34
AD16: JP13.5A, JP13.5B, U4.AD16
AD34: JP13.3A, JP13.3B, U4.AD34
BOOT: C1.2, R9.2, U4.BOOT
BOOT1: C32.2, R23.2, U6.BOOT
BOOT2: C51.2, R35.2, U9.BOOT
BOOT3: C70.2, R47.2, U12.BOOT
BOOT4: C89.2, R59.2, U15.BOOT
BOOT5: C108.2, R71.2, U18.BOOT
CC1: J5.A5, R8.2
CC2: J5.B5, R7.2
CC3: J10.B5, R21.2
CC4: J10.A5, R22.2
CC5: J17.B5, R33.2
CC6: J17.A5, R34.2
CC7: J24.B5, R45.2
CC8: J24.A5, R46.2
CC9: J31.B5, R57.2
CC10: J31.A5, R58.2
CC11: J38.B5, R69.2
CC12: J38.A5, R70.2
D0: JP20.6A, JP20.6B, U4.D0
D1: JP20.5A, JP20.5B, U4.D1
D2: JP20.4A, JP20.4B, U4.D2
D3: J6.1, U4.D3
D4: J14.3, U6.D38
D5: J14.2, JP43.1, U6.D36
D6: JP38.1A, JP38.1B, U6.D14
D7: JP38.2A, JP38.2B, U6.D8
D8: JP19.2A, JP19.2B, U4.D8
D9: JP19.4A, JP19.4B, U4.D9
D10: JP19.3A, JP19.3B, U4.D10
D11: JP38.3A, JP38.3B, U6.D10
D12: JP38.4A, JP38.4B, U6.D9
D13: JP38.6A, JP38.6B, U6.D15
D14: JP19.1A, JP19.1B, U4.D14
D15: JP19.6A, JP19.6B, U4.D15
D16: JP39.1A, JP39.1B, U6.D17
D17: JP20.1A, JP20.1B, U4.D17
D18: JP39.2A, JP39.2B, U6.D41
D19: JP39.4A, JP39.4B, U6.D2
D20: JP39.5A, JP39.5B, U6.D1
D21: JP39.6A, JP39.6B, U6.D0
D22: J14.1, U6.D3
D23: J21.3, U9.D38
D24: J21.2, JP65.1, U9.D36
D25: JP60.1A, JP60.1B, U9.D14
D26: JP60.2A, JP60.2B, U9.D8
D27: JP60.3A, JP60.3B, U9.D10
D28: JP60.4A, JP60.4B, U9.D9
D29: JP60.6A, JP60.6B, U9.D15
D30: JP61.1A, JP61.1B, U9.D17
D31: JP61.2A, JP61.2B, U9.D41
D32: JP61.4A, JP61.4B, U9.D2
D33: JP61.5A, JP61.5B, U9.D1
D34: JP61.6A, JP61.6B, U9.D0
D35: J21.1, U9.D3
D36: J6.2, JP21.1, U4.D36
D37: J28.3, U12.D38
D38: J6.3, U4.D38
D39: J28.2, JP87.1, U12.D36
D40: JP82.1A, JP82.1B, U12.D14
D40/SDA: J4.3, JP2.2A, JP2.2B, U4.D40
D40/SDA1: J9.3, JP29.2A, JP29.2B, U6.D40
D40/SDA2: J16.3, JP51.2A, JP51.2B, U9.D40
D40/SDA3: J23.3, JP73.2A, JP73.2B, U12.D40
D40/SDA4: J30.3, JP95.2A, JP95.2B, U15.D40
D40/SDA5: J37.3, JP117.2A, JP117.2B, U18.D40
D41: JP20.2A, JP20.2B, U4.D41
D42: JP82.2A, JP82.2B, U12.D8
D43: JP82.3A, JP82.3B, U12.D10
D44: JP82.4A, JP82.4B, U12.D9
D45: JP82.6A, JP82.6B, U12.D15
D46: JP83.1A, JP83.1B, U12.D17
D47: JP83.2A, JP83.2B, U12.D41
D48: JP83.4A, JP83.4B, U12.D2
D49: JP83.5A, JP83.5B, U12.D1
D50: JP83.6A, JP83.6B, U12.D0
D51: J28.1, U12.D3
D52: J35.3, U15.D38
D53: J35.2, JP109.1, U15.D36
D54: JP104.1A, JP104.1B, U15.D14
D55: JP104.2A, JP104.2B, U15.D8
D56: JP104.3A, JP104.3B, U15.D10
D57: JP104.4A, JP104.4B, U15.D9
D58: JP104.6A, JP104.6B, U15.D15
D59: JP105.1A, JP105.1B, U15.D17
D60: JP105.2A, JP105.2B, U15.D41
D61: JP105.4A, JP105.4B, U15.D2
D62: JP105.5A, JP105.5B, U15.D1
D63: JP105.6A, JP105.6B, U15.D0
D64: J35.1, U15.D3
D65: J42.3, U18.D38
D66: J42.2, JP131.1, U18.D36
D67: JP126.1A, JP126.1B, U18.D14
D68: JP126.2A, JP126.2B, U18.D8
D69: JP126.3A, JP126.3B, U18.D10
D70: JP126.4A, JP126.4B, U18.D9
D71: JP126.6A, JP126.6B, U18.D15
D72: JP127.1A, JP127.1B, U18.D17
D73: JP127.2A, JP127.2B, U18.D41
D74: JP127.4A, JP127.4B, U18.D2
D75: JP127.5A, JP127.5B, U18.D1
D76: JP127.6A, JP127.6B, U18.D0
D77: J42.1, U18.D3
D+: J5.A6, J5.B6, JP14.D+, U5.5
D+1: J10.A6, J10.B6, JP34.D+, U2.5
D+2: J17.A6, J17.B6, JP56.D+, U8.5
D+3: J24.A6, J24.B6, JP78.D+, U11.5
D+4: J31.A6, J31.B6, JP100.D+, U14.5
D+5: J38.A6, J38.B6, JP122.D+, U17.5
D-: J5.A7, J5.B7, JP14.D-, U5.6
D-1: J10.A7, J10.B7, JP34.D-, U2.6
D-2: J17.A7, J17.B7, JP56.D-, U8.6
D-3: J24.A7, J24.B7, JP78.D-, U11.6
D-4: J31.A7, J31.B7, JP100.D-, U14.6
D-5: J38.A7, J38.B7, JP122.D-, U17.6
GND: BT1.2, C2.1, C3.-, C4.2, C5.-, C6.-, C7.2, C9.2, C10.2, C11.1, C12.2, C13.1, C15.-, C16.2, C17.2, C18.2, C19.2, C28.2, E1.3, E1.6, E1.7, E1.8, J2.3, J2.5, J2.9, J3.GND, J4.1, J5.GND, J5.GND2, JP2.4A, JP2.4B, JP10.2A, JP10.2B, JP10.3A, JP10.3B, JP14.GND, JP16.1, LED1.C, LED2.C, R5.1, R7.1, R8.1, R9.1, R14.1, S1.1, S1.2, U3.2, U4.GND@1, U4.GND@22, U4.GND@38, U4.GND@39, U4.GND@47, U4.GND@59, U5.1
GND1: BT2.2, C14.1, C20.-, C21.2, C22.-, C24.2, C25.2, C26.-, C27.-, C29.2, C30.2, C31.2, C33.2, C34.2, C35.1, C36.1, C37.2, C38.2, E2.3, E2.6, E2.7, E2.8, J8.GND, J9.1, J10.GND, J10.GND2, J11.3, J11.5, J11.9, JP29.4A, JP29.4B, JP30.2A, JP30.2B, JP30.3A, JP30.3B, JP34.GND, JP37.1, LED3.C, LED4.C, R17.1, R21.1, R22.1, R23.1, R24.1, S2.1, S2.2, U1.2, U2.1, U6.GND@1, U6.GND@22, U6.GND@38, U6.GND@39, U6.GND@47, U6.GND@59
GND2: BT3.2, C39.1, C40.-, C41.2, C42.-, C44.2, C45.2, C46.-, C47.-, C48.2, C49.2, C50.2, C52.2, C53.2, C54.1, C55.1, C56.2, C57.2, E3.3, E3.6, E3.7, E3.8, J15.GND, J16.1, J17.GND, J17.GND2, J18.3, J18.5, J18.9, JP51.4A, JP51.4B, JP52.2A, JP52.2B, JP52.3A, JP52.3B, JP56.GND, JP59.1, LED5.C, LED6.C, R29.1, R33.1, R34.1, R35.1, R36.1, S3.1, S3.2, U7.2, U8.1, U9.GND@1, U9.GND@22, U9.GND@38, U9.GND@39, U9.GND@47, U9.GND@59
GND3: BT4.2, C58.1, C59.-, C60.2, C61.-, C63.2, C64.2, C65.-, C66.-, C67.2, C68.2, C69.2, C71.2, C72.2, C73.1, C74.1, C75.2, C76.2, E4.3, E4.6, E4.7, E4.8, J22.GND, J23.1, J24.GND, J24.GND2, J25.3, J25.5, J25.9, JP73.4A, JP73.4B, JP74.2A, JP74.2B, JP74.3A, JP74.3B, JP78.GND, JP81.1, LED7.C, LED8.C, R41.1, R45.1, R46.1, R47.1, R48.1, S4.1, S4.2, U10.2, U11.1, U12.GND@1, U12.GND@22, U12.GND@38, U12.GND@39, U12.GND@47, U12.GND@59
GND4: BT5.2, C77.1, C78.-, C79.2, C80.-, C82.2, C83.2, C84.-, C85.-, C86.2, C87.2, C88.2, C90.2, C91.2, C92.1, C93.1, C94.2, C95.2, E5.3, E5.6, E5.7, E5.8, J29.GND, J30.1, J31.GND, J31.GND2, J32.3, J32.5, J32.9, JP95.4A, JP95.4B, JP96.2A, JP96.2B, JP96.3A, JP96.3B, JP100.GND, JP103.1, LED9.C, LED10.C, R53.1, R57.1, R58.1, R59.1, R60.1, S5.1, S5.2, U13.2, U14.1, U15.GND@1, U15.GND@22, U15.GND@38, U15.GND@39, U15.GND@47, U15.GND@59
GND5: BT6.2, C96.1, C97.-, C98.2, C99.-, C101.2, C102.2, C103.-, C104.-, C105.2, C106.2, C107.2, C109.2, C110.2, C111.1, C112.1, C113.2, C114.2, E6.3, E6.6, E6.7, E6.8, J36.GND, J37.1, J38.GND, J38.GND2, J39.3, J39.5, J39.9, JP117.4A, JP117.4B, JP118.2A, JP118.2B, JP118.3A, JP118.3B, JP122.GND, JP125.1, LED11.C, LED12.C, R65.1, R69.1, R70.1, R71.1, R72.1, S6.1, S6.2, U16.2, U17.1, U18.GND@1, U18.GND@22, U18.GND@38, U18.GND@39, U18.GND@47, U18.GND@59
INSERT: J3.P$4, Q1.1, R4.1
INSERT1: J8.P$4, Q2.1, R13.1
INSERT2: J15.P$4, Q3.1, R28.1
INSERT3: J22.P$4, Q4.1, R40.1
INSERT4: J29.P$4, Q5.1, R52.1
INSERT5: J36.P$4, Q6.1, R64.1
unnamed: LED1.A, R1.2
unnamed: LED2.A, R2.1
unnamed: D4.C, D5.C, J1.2, JP15.1
unnamed: D2.A, R16.1
unnamed: C17.1, U5.4
unnamed: C11.2, U4.XO, Y1.P$2
unnamed: C13.2, U4.XI, Y1.P$1
unnamed: D3.A, R12.1
unnamed: JP2.3A, JP2.3B, JP16.2
unnamed: LED3.A, R10.1
unnamed: LED4.A, R6.2
unnamed: IC1.1, R17.2, R18.1
unnamed: D8.A, R20.1
unnamed: IC3.1, R14.2, R15.1
unnamed: D7.A, R19.1
unnamed: C30.1, U2.4
unnamed: D9.C, D10.C, J12.2, JP36.1
unnamed: C35.2, U6.XO, Y2.P$2
unnamed: C36.2, U6.XI, Y2.P$1
unnamed: JP29.3A, JP29.3B, JP37.2
unnamed: LED5.A, R26.1
unnamed: LED6.A, R25.2
unnamed: IC2.1, R29.2, R30.1
unnamed: D13.A, R32.1
unnamed: D12.A, R31.1
unnamed: C49.1, U8.4
unnamed: D14.C, D15.C, J19.2, JP58.1
unnamed: C54.2, U9.XO, Y3.P$2
unnamed: C55.2, U9.XI, Y3.P$1
unnamed: JP51.3A, JP51.3B, JP59.2
unnamed: LED7.A, R38.1
unnamed: LED8.A, R37.2
unnamed: IC4.1, R41.2, R42.1
unnamed: D18.A, R44.1
unnamed: D17.A, R43.1
unnamed: C68.1, U11.4
unnamed: D19.C, D20.C, J26.2, JP80.1
unnamed: C73.2, U12.XO, Y4.P$2
unnamed: C74.2, U12.XI, Y4.P$1
unnamed: JP73.3A, JP73.3B, JP81.2
unnamed: LED9.A, R50.1
unnamed: LED10.A, R49.2
unnamed: IC5.1, R53.2, R54.1
unnamed: D23.A, R56.1
unnamed: D22.A, R55.1
unnamed: C87.1, U14.4
unnamed: D24.C, D25.C, J33.2, JP102.1
unnamed: C92.2, U15.XO, Y5.P$2
unnamed: C93.2, U15.XI, Y5.P$1
unnamed: JP95.3A, JP95.3B, JP103.2
unnamed: LED11.A, R62.1
unnamed: LED12.A, R61.2
unnamed: IC6.1, R65.2, R66.1
unnamed: D28.A, R68.1
unnamed: D27.A, R67.1
unnamed: C106.1, U17.4
unnamed: D29.C, D30.C, J40.2, JP124.1
unnamed: C111.2, U18.XO, Y6.P$2
unnamed: C112.2, U18.XI, Y6.P$1
unnamed: JP117.3A, JP117.3B, JP125.2
PDMCLK: E1.4, JP22.2
PDMCLK1: E2.4, JP44.2
PDMCLK2: E3.4, JP66.2
PDMCLK3: E4.4, JP88.2
PDMCLK4: E5.4, JP110.2
PDMCLK5: E6.4, JP132.2
PDMDATA: E1.1, JP21.2
PDMDATA1: E2.1, JP43.2
PDMDATA2: E3.1, JP65.2
PDMDATA3: E4.1, JP87.2
PDMDATA4: E5.1, JP109.2
PDMDATA5: E6.1, JP131.2
PWRIN: D1.A, J3.VIN0
PWRIN1: D6.A, J8.VIN0
PWRIN2: D11.A, J15.VIN0
PWRIN3: D16.A, J22.VIN0
PWRIN4: D21.A, J29.VIN0
PWRIN5: D26.A, J36.VIN0
RXI-0: D3.C, J7.1, TP5.P$1, U4.RXI-0, U5.2
RXI-1: D7.C, J13.1, TP8.P$1, U2.2, U6.RXI-0
RXI-2: D12.C, J20.1, TP13.P$1, U8.2, U9.RXI-0
RXI-3: D17.C, J27.1, TP18.P$1, U11.2, U12.RXI-0
RXI-4: D22.C, J34.1, TP23.P$1, U14.2, U15.RXI-0
RXI-5: D27.C, J41.1, TP28.P$1, U17.2, U18.RXI-0
SHLD: J5.SHLD1, J5.SHLD2, J5.SHLD3, J5.SHLD4, J5.SHLD5, J5.SHLD6, J5.SHLD7, J5.SHLD8
SHLD1: J10.SHLD1, J10.SHLD2, J10.SHLD3, J10.SHLD4, J10.SHLD5, J10.SHLD6, J10.SHLD7, J10.SHLD8
SHLD2: J17.SHLD1, J17.SHLD2, J17.SHLD3, J17.SHLD4, J17.SHLD5, J17.SHLD6, J17.SHLD7, J17.SHLD8
SHLD3: J24.SHLD1, J24.SHLD2, J24.SHLD3, J24.SHLD4, J24.SHLD5, J24.SHLD6, J24.SHLD7, J24.SHLD8
SHLD4: J31.SHLD1, J31.SHLD2, J31.SHLD3, J31.SHLD4, J31.SHLD5, J31.SHLD6, J31.SHLD7, J31.SHLD8
SHLD5: J38.SHLD1, J38.SHLD2, J38.SHLD3, J38.SHLD4, J38.SHLD5, J38.SHLD6, J38.SHLD7, J38.SHLD8
SWDCK: J2.4, TP1.P$1, U4.SWDCK
SWDCK1: J11.4, TP4.P$1, U6.SWDCK
SWDCK2: J18.4, TP11.P$1, U9.SWDCK
SWDCK3: J25.4, TP16.P$1, U12.SWDCK
SWDCK4: J32.4, TP21.P$1, U15.SWDCK
SWDCK5: J39.4, TP26.P$1, U18.SWDCK
SWDIO: J2.2, TP2.P$1, U4.SWDIO
SWDIO1: J11.2, TP7.P$1, U6.SWDIO
SWDIO2: J18.2, TP12.P$1, U9.SWDIO
SWDIO3: J25.2, TP17.P$1, U12.SWDIO
SWDIO4: J32.2, TP22.P$1, U15.SWDIO
SWDIO5: J39.2, TP27.P$1, U18.SWDIO
TXO-0: D2.C, J7.2, TP6.P$1, U4.TXO-0, U5.3
TXO-1: D8.C, J13.2, TP9.P$1, U2.3, U6.TXO-0
TXO-2: D13.C, J20.2, TP14.P$1, U8.3, U9.TXO-0
TXO-3: D18.C, J27.2, TP19.P$1, U11.3, U12.TXO-0
TXO-4: D23.C, J34.2, TP24.P$1, U14.3, U15.TXO-0
TXO-5: D28.C, J41.2, TP29.P$1, U17.3, U18.TXO-0
USBVCC: C12.1, C15.+, F2.2, JP12.2, Q1.3
USBVCC1: C25.1, C26.+, F1.2, JP35.2, Q2.3
USBVCC2: C45.1, C46.+, F3.2, JP57.2, Q3.3
USBVCC3: C64.1, C65.+, F4.2, JP79.2, Q4.3
USBVCC4: C83.1, C84.+, F5.2, JP101.2, Q5.3
USBVCC5: C102.1, C103.+, F6.2, JP123.2, Q6.3
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

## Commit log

2019-05-22 Fixes from design review. Route away from antenna.
    [BlackBoard-Artemis-ATP.brd, BlackBoard-Artemis-ATP.sch]
2019-05-22 Add panel files
    [BlackBoard-Artemis-ATP.brd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]
2019-05-24 Moved SWDIO test point. Removed TP5/6.
    [BlackBoard-Artemis-ATP.brd, BlackBoard-Artemis-ATP.sch]
2019-05-29 Move TP for easier testing. Remove TP on serial. Adjust sch blocks.
    [BlackBoard-Artemis-ATP.brd, BlackBoard-Artemis-ATP.sch]
2019-06-20 Add ignore. Add panel files.
    [BlackBoard-Artemis-ATP-Panel.brd, BlackBoard-Artemis-ATP.brd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]

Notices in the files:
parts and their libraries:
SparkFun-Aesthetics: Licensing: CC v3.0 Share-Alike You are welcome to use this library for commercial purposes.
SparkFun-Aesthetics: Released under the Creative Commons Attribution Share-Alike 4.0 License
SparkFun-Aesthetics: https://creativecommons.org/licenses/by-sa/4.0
